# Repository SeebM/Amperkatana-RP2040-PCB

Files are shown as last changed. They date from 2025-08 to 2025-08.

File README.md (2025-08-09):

# Modification 08/2025
This PCB is based on the template below and should - once it is finished - fit into a Ampersand keyboard case and compatible other cases like dizzyskizzos Amperconcrete.

# Keyboard PCB Integration with Microcontrollers

This GitHub project provides guidance on integrating microcontrollers into keyboard PCBs. It focuses on the RP2040 microcontroller from the Raspberry Pi foundation, which offers several features such as a dual-core Arm Cortex-M0+ processor, multiple communication interfaces, and QMK/Via/Vial support.

Schematic

## Schematic Capture

Before proceeding with board layout, it is important to understand the steps involved in schematic capture. The README provides an overview of the RP2040 microcontroller, including its integrated 3.3V->1.1V regulator, pin connections like TESTEN and RUN_, and the need for additional components such as decoupling capacitors.

## Power Supply and USB Bootloader

The RP2040 is powered through USB and features a built-in USB bootloader for easy programming. The README mentions the use of a 3.3V fixed regulator, USBLC6 ESD protection IC, PTC resettable fuse, and a ferrite bead for EMI suppression.

## PCB Connectors

The project includes information about the USB-C port, its orientation detection pins (CC1/CC2), and the 5.1k resistors used for USB power delivery. Additionally, a JST connector is introduced for use with a Unified Daughter Board.

## Crystal and External Flash

A crystal is employed to provide accurate timing for USB functionality. The README also covers the connections to the RP2040's external flash, including buttons for forcing the ROM bootloader and resetting the microcontroller.

## Indicator LED and Switch Matrix

An indicator LED example for caps lock indication is given, along with considerations for selecting an appropriate LED resistor value. The README highlights the use of diodes in the switch matrix to prevent "ghosting" and enable n-key rollover.

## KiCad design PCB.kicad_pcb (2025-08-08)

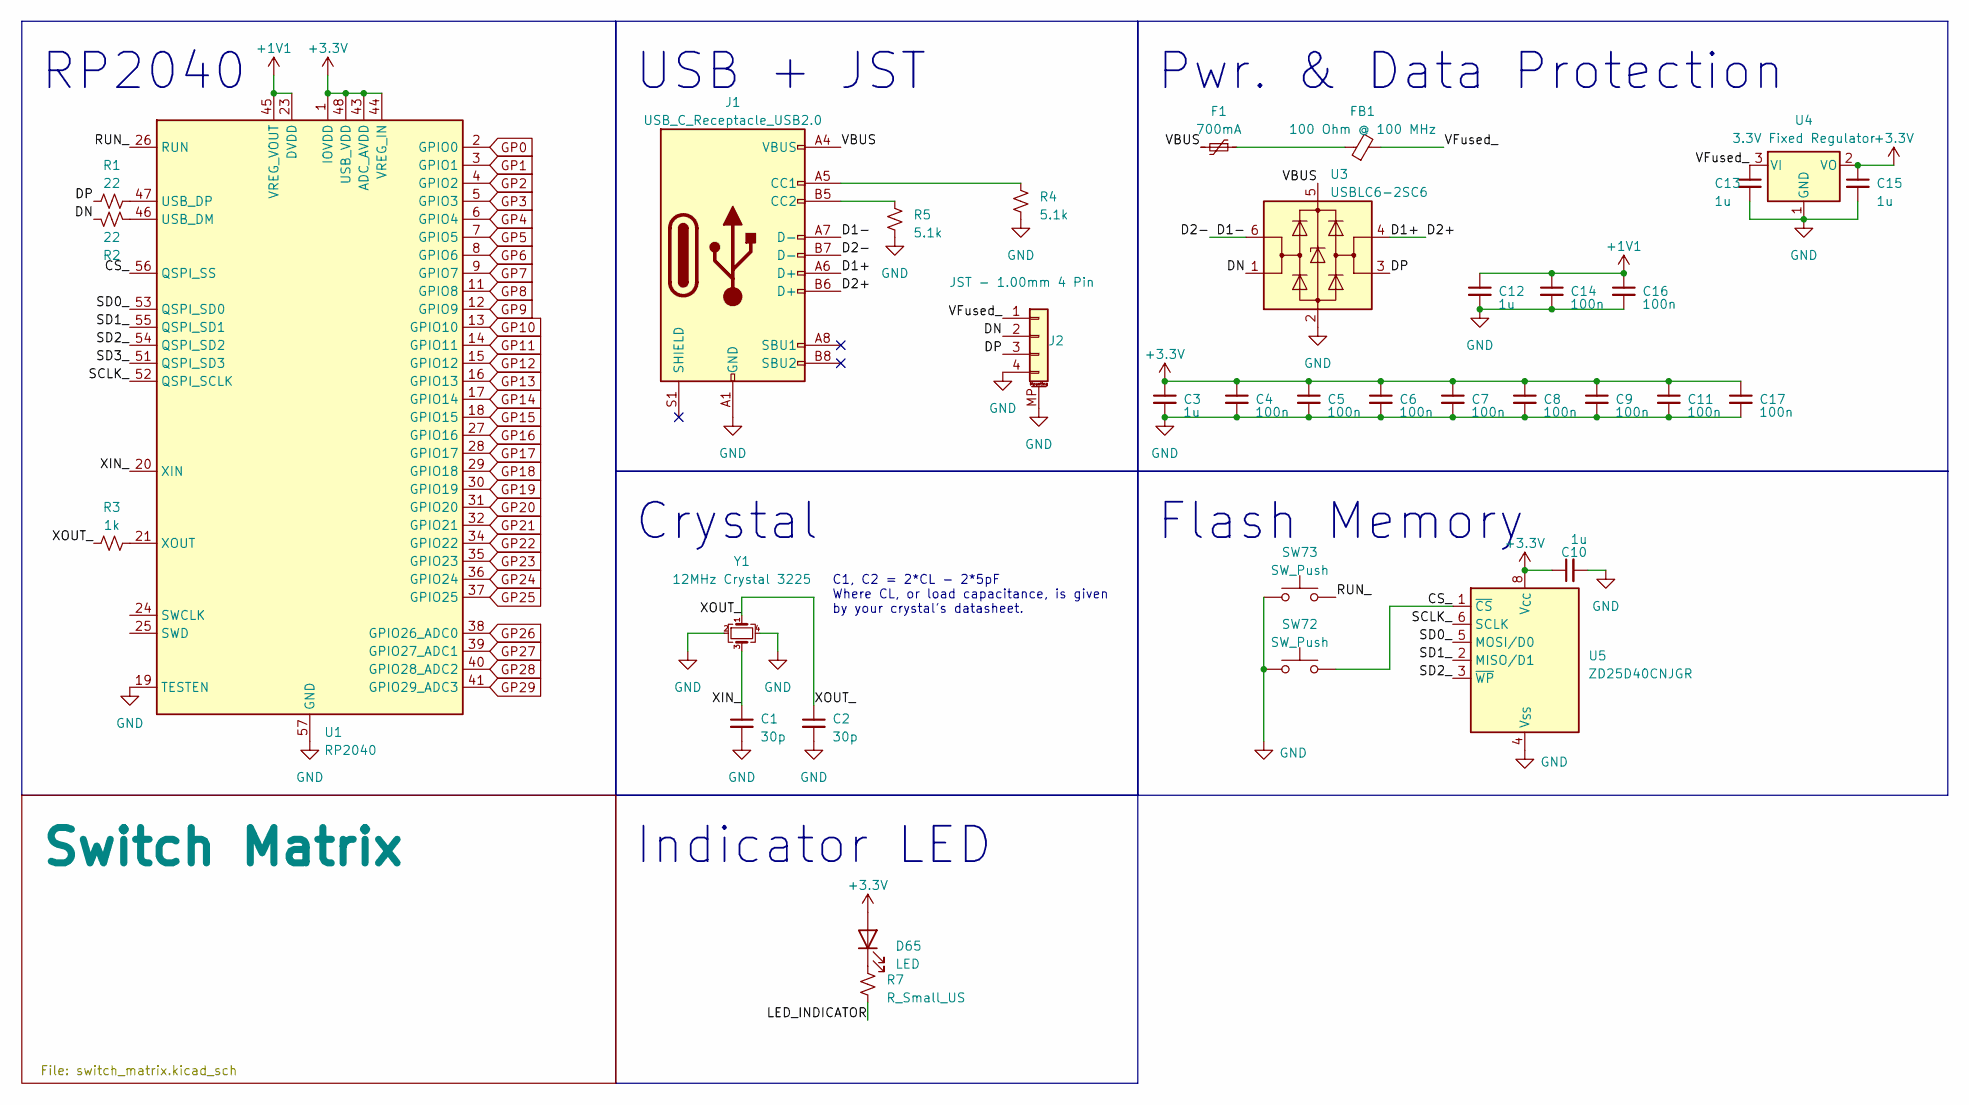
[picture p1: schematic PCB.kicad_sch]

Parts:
C1, C2: 30p; C_0402_1005Metric; LCSC C1562
C3, C10, C12, C13, C15: 1u; C_0402_1005Metric; LCSC C52923
C4, C5, C6, C7, C8, C9, C11, C14, C16, C17: 100n; C_0402_1005Metric; LCSC C1525
D65: LED; LED_MX_3mm
F1: 700mA; Fuse_0402_1005Metric; LCSC C914086
FB1: 100 Ohm @ 100 MHz; L_0402_1005Metric; LCSC C85812
J1: USB_C_Receptacle_USB2.0; USB_C_Receptacle_GCT_USB4085
J2: JST - 1.00mm 4 Pin; JST_SH_SM04B-SRSS-TB_1x04-1MP_P1.00mm_Horizontal; LCSC C160404
R1, R2: 22; R_0402_1005Metric; LCSC C25152
R3: 1k; R_0402_1005Metric; LCSC C106235
R4, R5: 5.1k; R_0402_1005Metric; LCSC C25905
R7: R_Small_US; R_0402_1005Metric
SW72, SW73: SW_Push; SW_SPST_SKQG_WithoutStem; LCSC C115351
U1: RP2040; QFN-56-1EP_7x7mm_P0.4mm_EP3.2x3.2mm_ThermalVias; LCSC C2040
U3: USBLC6-2SC6; SOT-23-6; LCSC C558442
U4: 3.3V Fixed Regulator; TSOT-23; LCSC C150715
U5: ZD25D40CNJGR; USON-8_1.5x1.5mm_P0.45mm; LCSC C3646778
Y1: 12MHz Crystal 3225; Crystal_SMD_3225-4Pin_3.2x2.5mm; LCSC C9002

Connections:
+1V1: C12.1, C14.1, C16.1, U1.23 (DVDD), U1.45 (VREG_VOUT), U1.50 (DVDD)
+3.3V: C3.1, C4.1, C5.1, C6.1, C7.1, C8.1, C9.1, C10.1, C11.1, C15.1, C17.1, D65.2 (A), U1.1 (IOVDD), U1.10 (IOVDD), U1.22 (IOVDD), U1.33 (IOVDD), U1.42 (IOVDD), U1.43 (ADC_AVDD), U1.44 (VREG_IN), U1.48 (USB_VDD), U1.49 (IOVDD), U4.2 (VO), U5.8 (V_{CC})
/CS_: SW72.2, U1.56 (QSPI_SS), U5.1 (~CS)
/D1+: J1.A6 (D+), J1.B6 (D+), U3.4 (I/O2)
/D1-: J1.A7 (D-), J1.B7 (D-), U3.6 (I/O1)
/DN: J2.2, R2.2, U3.1 (I/O1)
/DP: J2.3, R1.1, U3.3 (I/O2)
/LED_INDICATOR: R7.2
/RUN_: SW73.2, U1.26 (RUN)
/SCLK_: U1.52 (QSPI_SCLK), U5.6 (SCLK)
/SD0_: U1.53 (QSPI_SD0), U5.5 (MOSI/D0)
/SD1_: U1.55 (QSPI_SD1), U5.2 (MISO/D1)
/SD2_: U1.54 (QSPI_SD2), U5.3 (~WP)
/SD3_: U1.51 (QSPI_SD3)
/VBUS: F1.2, J1.A4 (VBUS), J1.A9 (VBUS), J1.B4 (VBUS), J1.B9 (VBUS), U3.5 (VBUS)
/VFused_: C13.1, FB1.2, J2.1, U4.3 (VI)
/XIN_: C1.1, U1.20 (XIN), Y1.3
/XOUT_: C2.1, R3.1, Y1.1
Col0: U1.2 (GPIO0); also elsewhere on the board
Col1: U1.3 (GPIO1); also elsewhere on the board
Col2: U1.4 (GPIO2); also elsewhere on the board
Col3: U1.5 (GPIO3); also elsewhere on the board
Col4: U1.6 (GPIO4); also elsewhere on the board
Col5: U1.7 (GPIO5); also elsewhere on the board
Col6: U1.8 (GPIO6); also elsewhere on the board
Col7: U1.9 (GPIO7); also elsewhere on the board
Col8: U1.11 (GPIO8); also elsewhere on the board
Col9: U1.12 (GPIO9); also elsewhere on the board
Col10: U1.13 (GPIO10); also elsewhere on the board
Col11: U1.14 (GPIO11); also elsewhere on the board
Col12: U1.15 (GPIO12); also elsewhere on the board
GND: C1.2, C2.2, C3.2, C4.2, C5.2, C6.2, C7.2, C8.2, C9.2, C10.2, C11.2, C12.2, C13.2, C14.2, C15.2, C16.2, C17.2, J1.A1 (GND), J1.A12 (GND), J1.B1 (GND), J1.B12 (GND), J2.4, J2.MP (MountPin), R4.1, R5.1, SW72.1, SW73.1, U1.19 (TESTEN), U1.57 (GND), U3.2 (GND), U4.1 (GND), U5.4 (V_{SS}), U5.9 (PAD/V_{SS}), Y1.2, Y1.4
GP13: U1.16 (GPIO13)
GP14: U1.17 (GPIO14); also elsewhere on the board
GP15: U1.18 (GPIO15); also elsewhere on the board
GP16: U1.27 (GPIO16); also elsewhere on the board
GP17: U1.28 (GPIO17); also elsewhere on the board
GP18: U1.29 (GPIO18)
GP19: U1.30 (GPIO19)
GP20: U1.31 (GPIO20)
GP21: U1.32 (GPIO21)
GP22: U1.34 (GPIO22)
GP23: U1.35 (GPIO23)
GP24: U1.36 (GPIO24)
GP25: U1.37 (GPIO25)
GP26: U1.38 (GPIO26_ADC0)
GP27: U1.39 (GPIO27_ADC1)
GP28: U1.40 (GPIO28_ADC2)
GP29: U1.41 (GPIO29_ADC3)
unnamed: D65.1 (K), R7.1
unnamed: F1.1, FB1.1
unnamed: J1.A5 (CC1), R4.2
unnamed: J1.B5 (CC2), R5.2
unnamed: R2.1, U1.46 (USB_DM)
unnamed: R1.2, U1.47 (USB_DP)
unnamed: R3.2, U1.21 (XOUT)

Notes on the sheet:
Flash Memory
Pwr. & Data Protection
C1, C2 = 2*CL - 2*5pF Where CL, or load capacitance, is given by your crystal's datasheet.
Indicator LED
Crystal
RP2040
USB + JST

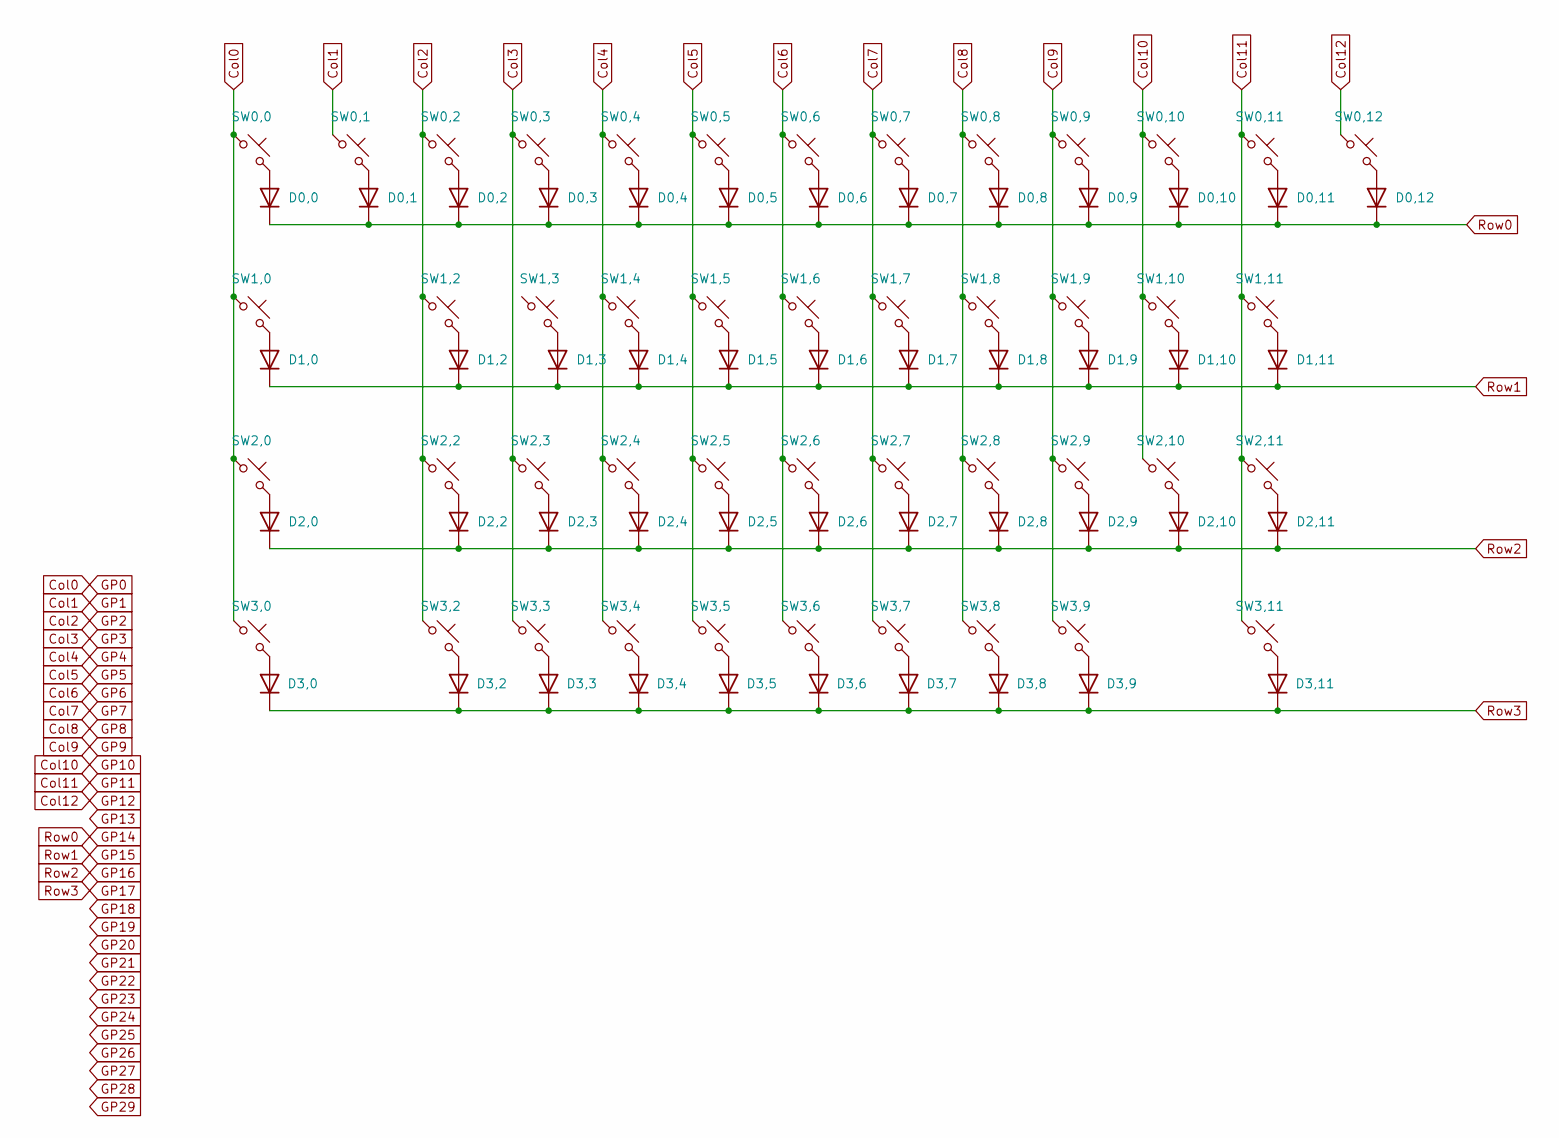
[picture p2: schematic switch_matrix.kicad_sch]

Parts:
D0,0, D0,1, D0,2, D0,3, D0,4, D0,5, D0,6, D0,7, D0,8, D0,9, D0,10, D0,11, D0,12, D1,0, D1,2, D1,3, D1,4, D1,5, D1,6, D1,7, D1,8, D1,9, D1,10, D1,11, D2,0, D2,2, D2,3, D2,4, D2,5, D2,6, D2,7, D2,8, D2,9, D2,10, D2,11, D3,0, D3,2, D3,3, D3,4, D3,5, D3,6, D3,7, D3,8, D3,9, D3,11: 1N4148W; D_SOD-123
SW0,0, SW0,1, SW0,2, SW0,3, SW0,4, SW0,5, SW0,6, SW0,7, SW0,8, SW0,9, SW0,10, SW0,11, SW1,2, SW1,3, SW1,4, SW1,5, SW1,6, SW1,7, SW1,8, SW1,9, SW1,10, SW2,2, SW2,3, SW2,4, SW2,5, SW2,6, SW2,7, SW2,8, SW2,9, SW2,10, SW3,0, SW3,2, SW3,3, SW3,6, SW3,11: MX_SW_solder; SW_MX_1u
SW0,12, SW2,0: MX_SW_solder; SW_MX_1.5u
SW1,0: MX_SW_solder; SW_MX_1.75u
SW1,11: MX_SW_solder; STAB_MX_P_2.25u
SW2,11: MX_SW_solder; STAB_MX_P_2u
SW3,4, SW3,7, SW3,8, SW3,9: MX_SW_solder; SW_MX_1.25u
SW3,5: MX_SW_solder; STAB_MX_P_3u

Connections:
Col0: SW0,0.1, SW1,0.1, SW2,0.1, SW3,0.1; also elsewhere on the board
Col1: SW0,1.1; also elsewhere on the board
Col2: SW0,2.1, SW1,2.1, SW2,2.1, SW3,2.1; also elsewhere on the board
Col3: SW0,3.1, SW2,3.1, SW3,3.1; also elsewhere on the board
Col4: SW0,4.1, SW1,4.1, SW2,4.1, SW3,4.1; also elsewhere on the board
Col5: SW0,5.1, SW1,5.1, SW2,5.1, SW3,5.1; also elsewhere on the board
Col6: SW0,6.1, SW1,6.1, SW2,6.1, SW3,6.1; also elsewhere on the board
Col7: SW0,7.1, SW1,7.1, SW2,7.1, SW3,7.1; also elsewhere on the board
Col8: SW0,8.1, SW1,8.1, SW2,8.1, SW3,8.1; also elsewhere on the board
Col9: SW0,9.1, SW1,9.1, SW2,9.1, SW3,9.1; also elsewhere on the board
Col10: SW0,10.1, SW1,10.1, SW2,10.1; also elsewhere on the board
Col11: SW0,11.1, SW1,11.1, SW2,11.1, SW3,11.1; also elsewhere on the board
Col12: SW0,12.1; also elsewhere on the board
GP14: D0,0.1 (K), D0,1.1 (K), D0,2.1 (K), D0,3.1 (K), D0,4.1 (K), D0,5.1 (K), D0,6.1 (K), D0,7.1 (K), D0,8.1 (K), D0,9.1 (K), D0,10.1 (K), D0,11.1 (K), D0,12.1 (K); also elsewhere on the board
GP15: D1,0.1 (K), D1,2.1 (K), D1,3.1 (K), D1,4.1 (K), D1,5.1 (K), D1,6.1 (K), D1,7.1 (K), D1,8.1 (K), D1,9.1 (K), D1,10.1 (K), D1,11.1 (K); also elsewhere on the board
GP16: D2,0.1 (K), D2,2.1 (K), D2,3.1 (K), D2,4.1 (K), D2,5.1 (K), D2,6.1 (K), D2,7.1 (K), D2,8.1 (K), D2,9.1 (K), D2,10.1 (K), D2,11.1 (K); also elsewhere on the board
GP17: D3,0.1 (K), D3,2.1 (K), D3,3.1 (K), D3,4.1 (K), D3,5.1 (K), D3,6.1 (K), D3,7.1 (K), D3,8.1 (K), D3,9.1 (K), D3,11.1 (K); also elsewhere on the board
unnamed: D0,0.2 (A), SW0,0.2
unnamed: D0,1.2 (A), SW0,1.2
unnamed: D0,2.2 (A), SW0,2.2
unnamed: D0,3.2 (A), SW0,3.2
unnamed: D0,4.2 (A), SW0,4.2
unnamed: D0,5.2 (A), SW0,5.2
unnamed: D0,6.2 (A), SW0,6.2
unnamed: D0,7.2 (A), SW0,7.2
unnamed: D0,8.2 (A), SW0,8.2
unnamed: D0,9.2 (A), SW0,9.2
unnamed: D0,10.2 (A), SW0,10.2
unnamed: D0,11.2 (A), SW0,11.2
unnamed: D0,12.2 (A), SW0,12.2
unnamed: D1,0.2 (A), SW1,0.2
unnamed: D1,2.2 (A), SW1,2.2
unnamed: D1,3.2 (A), SW1,3.2
unnamed: D1,4.2 (A), SW1,4.2
unnamed: D1,5.2 (A), SW1,5.2
unnamed: D1,6.2 (A), SW1,6.2
unnamed: D1,7.2 (A), SW1,7.2
unnamed: D1,8.2 (A), SW1,8.2
unnamed: D1,9.2 (A), SW1,9.2
unnamed: D1,10.2 (A), SW1,10.2
unnamed: D1,11.2 (A), SW1,11.2
unnamed: D2,0.2 (A), SW2,0.2
unnamed: D2,2.2 (A), SW2,2.2
unnamed: D2,3.2 (A), SW2,3.2
unnamed: D2,4.2 (A), SW2,4.2
unnamed: D2,5.2 (A), SW2,5.2
unnamed: D2,6.2 (A), SW2,6.2
unnamed: D2,7.2 (A), SW2,7.2
unnamed: D2,8.2 (A), SW2,8.2
unnamed: D2,9.2 (A), SW2,9.2
unnamed: D2,10.2 (A), SW2,10.2
unnamed: D2,11.2 (A), SW2,11.2
unnamed: D3,0.2 (A), SW3,0.2
unnamed: D3,2.2 (A), SW3,2.2
unnamed: D3,3.2 (A), SW3,3.2
unnamed: D3,4.2 (A), SW3,4.2
unnamed: D3,5.2 (A), SW3,5.2
unnamed: D3,6.2 (A), SW3,6.2
unnamed: D3,7.2 (A), SW3,7.2
unnamed: D3,8.2 (A), SW3,8.2
unnamed: D3,9.2 (A), SW3,9.2
unnamed: D3,11.2 (A), SW3,11.2

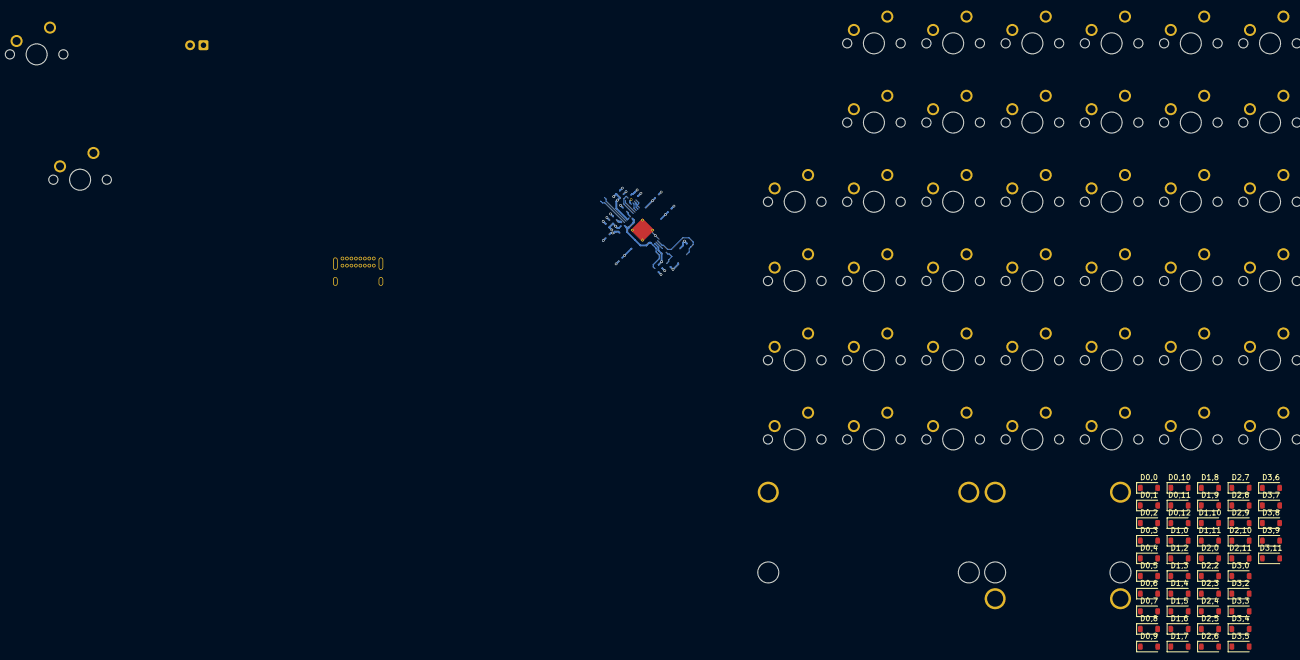
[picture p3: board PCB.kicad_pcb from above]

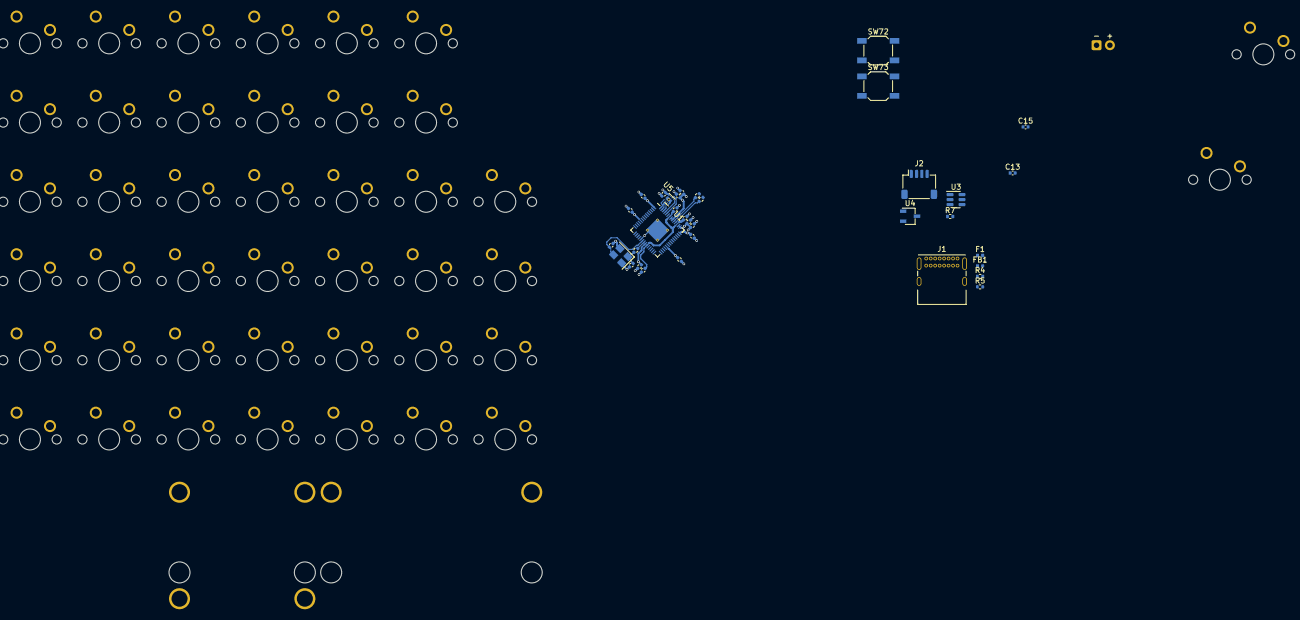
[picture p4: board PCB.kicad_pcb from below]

Board: 4 copper layers, 125 parts (34 on the bottom side), 83 nets.

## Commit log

2025-08-08 Update Schematic with keyboard layout
    [PCB.kicad_pcb, PCB.kicad_sch, switch_matrix.kicad_sch]
2025-08-08 First pcb footprints
    [PCB.kicad_pcb]
